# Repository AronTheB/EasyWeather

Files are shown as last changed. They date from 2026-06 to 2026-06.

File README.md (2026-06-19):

# ESP32 and BME280 based temperature, humidity, and barometric pressure measurer

## Zine
Zine

## Description

### Made for [Fallout](https://fallout.hackclub.com/) during a online weekend hackathon

### Why did i make this

I always had this idea, because i never know what to wear outside before leaving my house and I can't be hassled to check the weather app, so i will place this at the door window, so i can look and and check the temperature and other weather stats before leaving.

### How to build

Download the Gerber files and the 3d models and print them out. (I recomend JLCPCB and Prining Leigion). Order all the parts from the BOM section. After everything arrives solder the components togeather with the board and put the PCB in the case and Screw it in with a 2mm Screw. After close the box and screw it in with 3mm Screws. Connect the ESP32 to your computer and flash it with the firmware.

### How to use

After flashing it, turn the ESP32 back on and it should start automaticly. If everything worked out it should start showing the data on the OLED screen.

## KICAD

### Schematic



### PCB layout



### PCB Render (Front/Back)



## FUSION (Front/Back)



## BOM

| NAME | LINK | PRICE | QUANTITY | Need To buy? |
|---|---|---|---|---|
| XIAO ESP32-S3 | [AliExpress](https://www.aliexpress.com/item/1005007341749305.html) | $10,35 | 1 | Yes |
| BME280 | [AliExpress](https://www.aliexpress.com/item/1005006982994037.html) | $1,82 | 1 | Yes |
| 4,7k Resistors | [AliExpress](https://www.aliexpress.com/item/1005007345052730.html) | $1,36 | 1 | Yes |
| 3D Case | JLC3DP | $2,79 | 1 | Yes |
| PCB | JLCPCB | $5,00 | 1 | Yes |
| **TOTAL** | | **$23,53** | | |

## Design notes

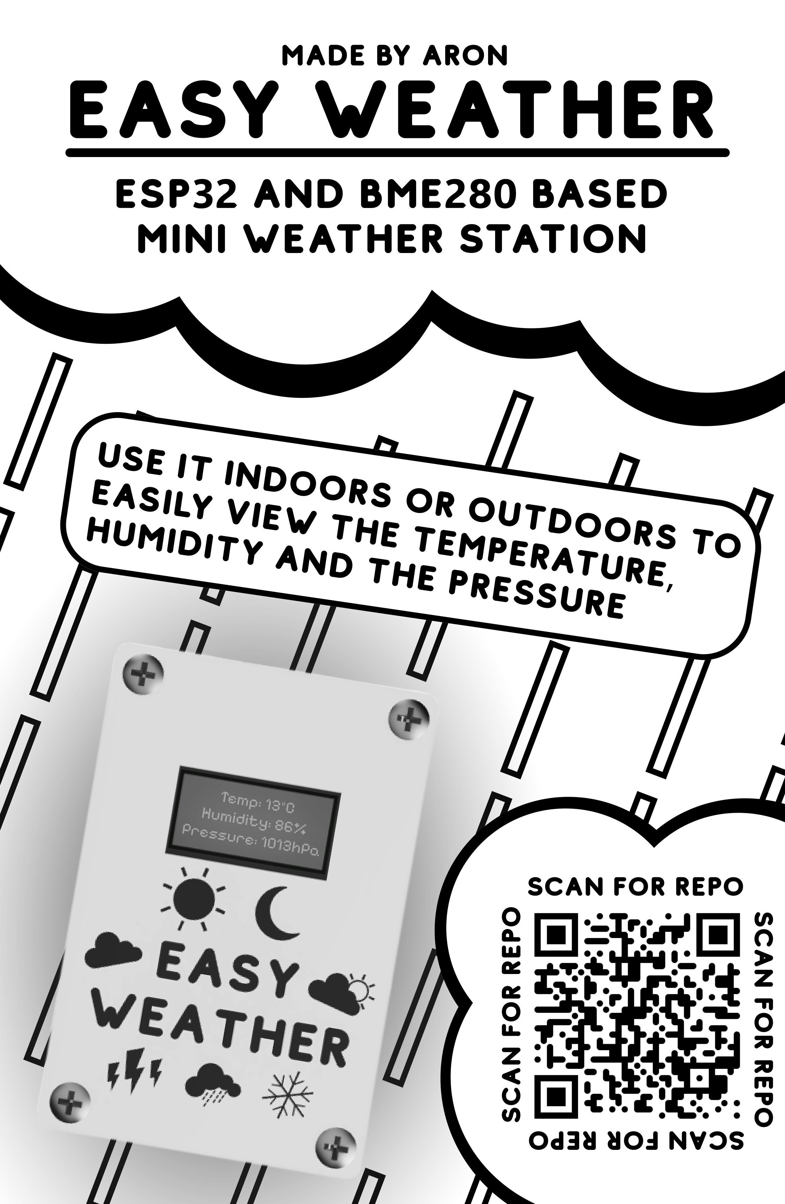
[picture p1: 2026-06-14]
Zine/Zine.jpg

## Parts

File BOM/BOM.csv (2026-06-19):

NAME | LINK | PRICE | QUANTITY | Need To buy?
XIAO ESP32-S3 | https://www.aliexpress.com/item/1005007341749305.html | $10,35 | 1 | Yes
BME280 | https://www.aliexpress.com/item/1005006982994037.html | $1,82 | 1 | Yes
4,7k Resistors | https://www.aliexpress.com/item/1005007345052730.html | 1,36 | 1 | Yes
3D Case | JLC3DP | $2,79 | 1 | Yes
PCB | JLCPCB | $5,00 | 1 | Yes
TOTAL: |  | $23,53

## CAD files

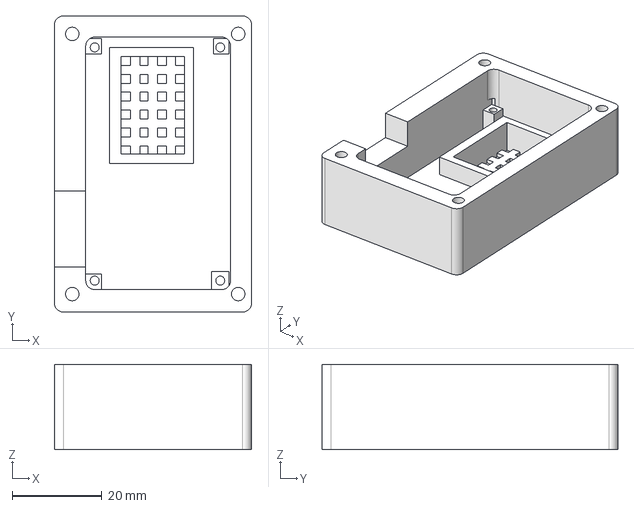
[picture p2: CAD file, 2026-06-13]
CAD/EasyWeatherBottom.step
44.0 x 66.0 x 19.0 mm

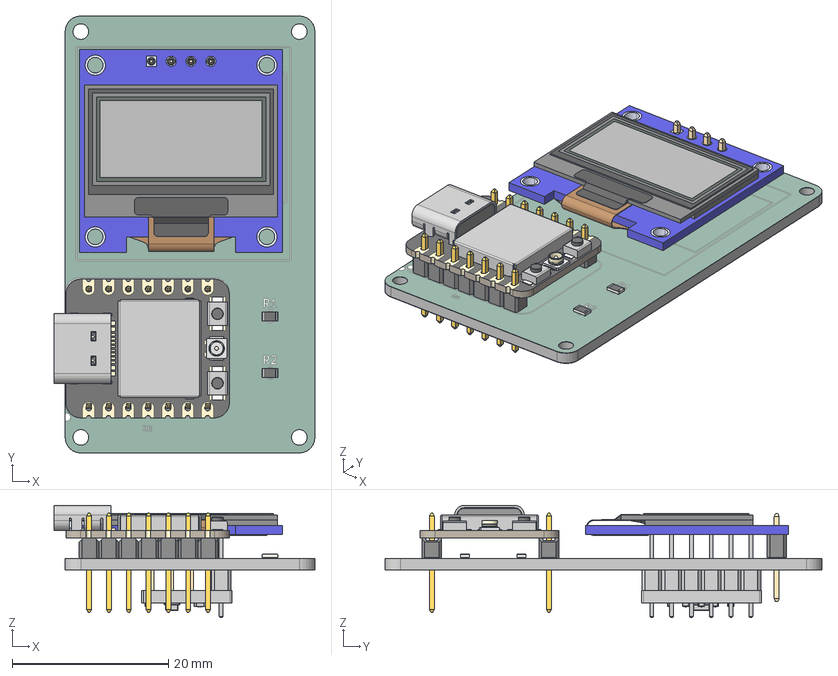
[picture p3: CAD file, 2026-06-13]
PCB/EasyWeather.step
33.4 x 56.0 x 14.4 mm
R_0805_2012Metric x 2
DM-OLED096-636_Module
DM-OLED096-636_Panel
BOSS-EXTRUDE14_8_
BOSS-EXTRUDE7_4_
BOSS-EXTRUDE7_3_
BOSS-EXTRUDE14_4_
BOSS-EXTRUDE14_2_
BOSS-EXTRUDE14_11_
BOSS-EXTRUDE7_7_
BOSS-EXTRUDE14_9_
BOSS-EXTRUDE14_3_
BOSS-EXTRUDE14_7_
MIRROR2
BOSS-EXTRUDE14_5_
BOSS-EXTRUDE14_12_
BOSS-EXTRUDE7_8_
BOSS-EXTRUDE7_1_
BOSS-EXTRUDE14_10_
BOSS-EXTRUDE7_9_
BOSS-EXTRUDE14_6_
BOSS-EXTRUDE14_1_
BOSS-EXTRUDE7_6_
BOSS-EXTRUDE7_2_
CUT-EXTRUDE5
BOSS-EXTRUDE7_5_
U.FL Connector v1
Button (1) x 2
Shield
EasyWeather_silkscreen x 2
EasyWeather_soldermask x 2
EasyWeather_PCB

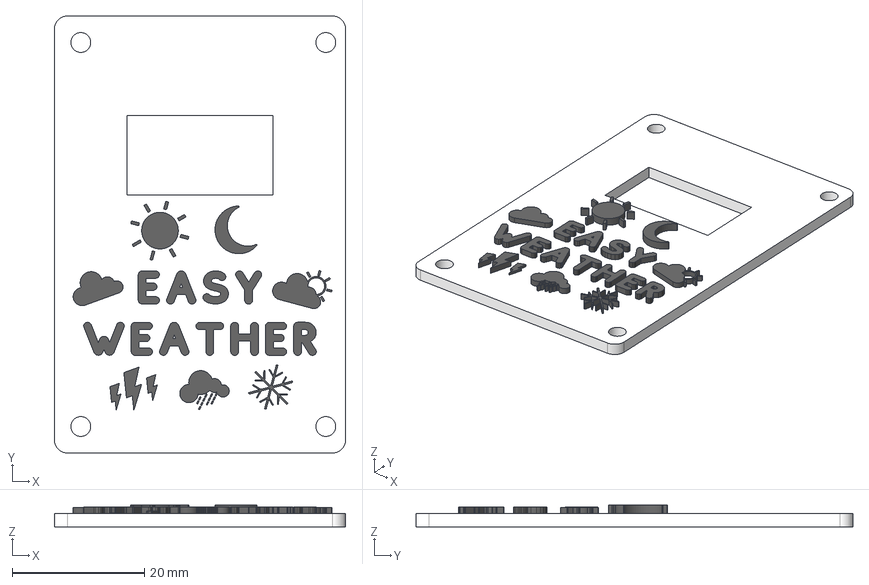
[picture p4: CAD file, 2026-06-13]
CAD/EasyWeatherTop.step
44.0 x 66.0 x 3.28 mm

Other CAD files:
CAD/EasyWeatherBottom.f3z

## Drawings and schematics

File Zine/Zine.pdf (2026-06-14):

# EASY WEATHER Made by Aron

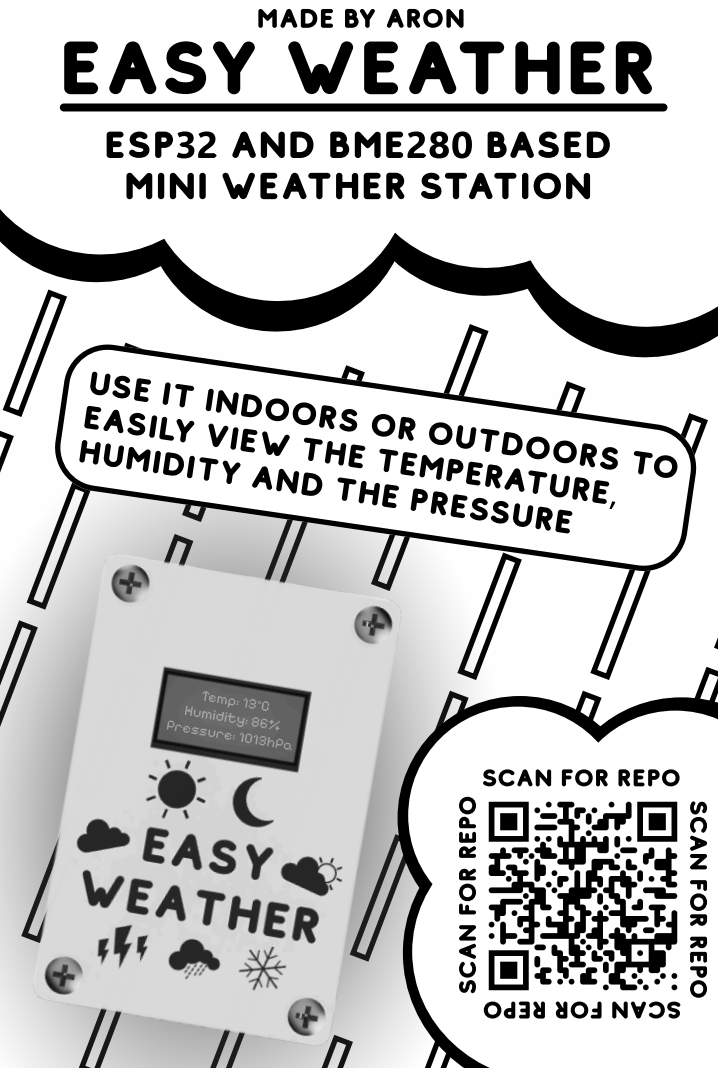
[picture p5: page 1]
Temp: 13°C Humidity: 86% Pressure: 1013hPa; SCAN; FOR REPO

ESP32 and BME280 based
mini weather station

Use it indoors or Outdoors to

easily view the temperature,

humidity and the pressure

SCAN FOR REPO

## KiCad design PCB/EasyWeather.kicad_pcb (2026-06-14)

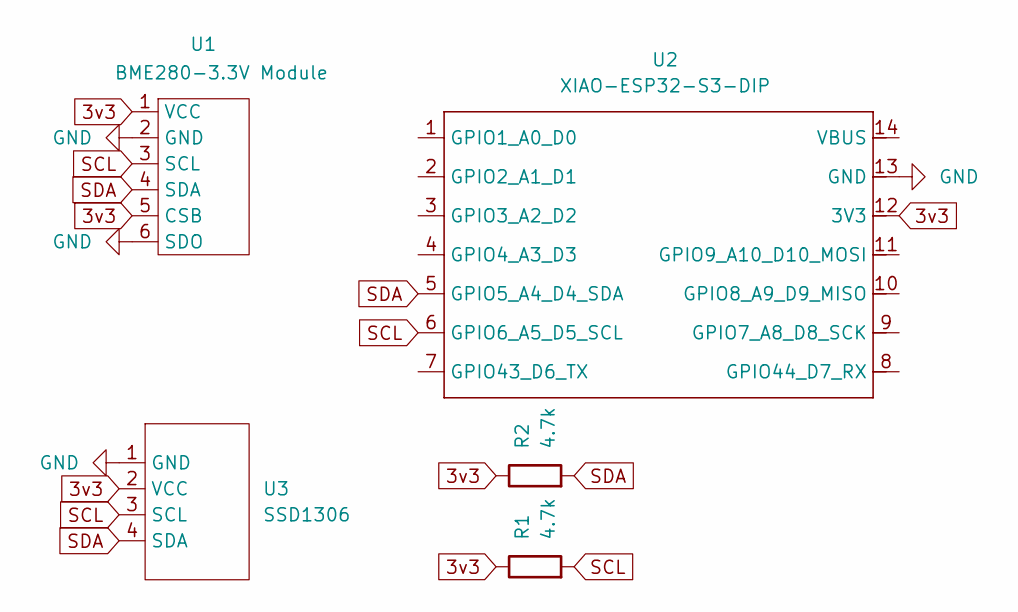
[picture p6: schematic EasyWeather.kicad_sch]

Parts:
R1, R2: 4.7k; R_0805_2012Metric_Pad1.20x1.40mm_HandSolder
U1: BME280-3.3V Module; BME280-3.3V
U2: XIAO-ESP32-S3-DIP
U3: SSD1306; 128x64OLED

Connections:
3v3: R1.1, R2.1, U1.1 (VCC), U1.5 (CSB), U2.12 (3V3), U3.2 (VCC)
GND: U1.2 (GND), U1.6 (SDO), U2.13 (GND), U3.1 (GND)
SCL: R1.2, U1.3 (SCL), U2.6 (GPIO6_A5_D5_SCL), U3.3 (SCL)
SDA: R2.2, U1.4 (SDA), U2.5 (GPIO5_A4_D4_SDA), U3.4 (SDA)

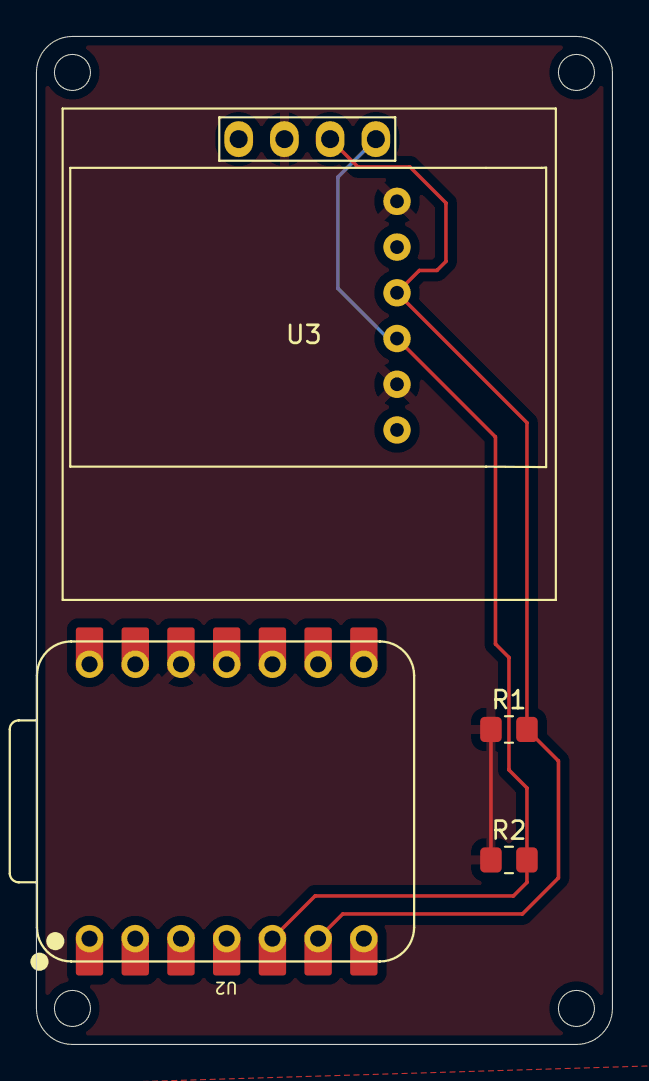
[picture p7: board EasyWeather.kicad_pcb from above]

Board: 2 copper layers, 32.0 x 56.0 mm, 5 parts (1 on the bottom side), 4 nets.

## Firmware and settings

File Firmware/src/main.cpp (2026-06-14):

#include <Wire.h>
#include <Adafruit_Sensor.h>
#include <Adafruit_BME280.h>
#include <WiFi.h>
#include <Adafruit_SSD1306.h>

#define SEALEVELPRESSURE_HPA (1013.25)
#define SCREEN_WIDTH 128
#define SCREEN_HEIGHT 64
#define OLED_RESET -1
Adafruit_SSD1306 display(SCREEN_WIDTH, SCREEN_HEIGHT, &Wire, OLED_RESET);
Adafruit_BME280 bme; // I2C

const char* ssid = "123";
const char* password = "123";
WiFiServer server(80);

unsigned long delayTime;

void setup() {
    Serial.begin(9600);
    Serial.println(F("BME280 test"));

    if (! bme.begin(0x77, &Wire)) {
        Serial.println("Could not find a valid BME280 sensor, check wiring!");
        while (1);
    }

    if (!display.begin(SSD1306_SWITCHCAPVCC, 0x3C)) {
        Serial.println("Could not find SSD1306!");
        while (1);
    }
    display.clearDisplay();
    display.setTextColor(SSD1306_WHITE);

    display.setTextSize(1);
    display.setCursor(0, 0);
    display.print("Connecting WiFi...");
    display.display();

    Serial.print("Connecting to ");
    Serial.println(ssid);
    WiFi.begin(ssid, password);
    while (WiFi.status() != WL_CONNECTED) {
      delay(500);
      Serial.print(".");
    }

    display.clearDisplay();
    display.setCursor(0, 0);
    display.print("WiFi connected!");
    display.setCursor(0, 10);
    display.print(WiFi.localIP());
    display.display();
    delay(2000);

    server.begin();
    delayTime = 5000;
}

void loop() {
    bme.takeForcedMeasurement();
    
    printValues();
    delay(delayTime);
}

// Add webserver later
void printValues() {
    float temperature = bme.readTemperature();
    float humidity = bme.readHumidity();
    float altitude = bme.readAltitude(SEALEVELPRESSURE_HPA);
    float pressure = bme.readPressure() / 100.0F;

    Serial.printf("Temp: %.1f C | Pressure: %.1f hPa | Alt: %.1f m | Hum: %.1f%%\n",temperature, pressure, altitude, humidity);

    display.clearDisplay();
    display.setTextSize(1);
    display.setCursor(0, 0);
    display.printf("Temp: %.1f C\n", temperature);

    display.setCursor(0, 16);
    display.printf("Pressure: %.1f hPa\n", pressure);

    display.setCursor(0, 32);
    display.printf("Humidity: %.1f%%\n", humidity);

    display.setCursor(0, 48);
    display.printf("Altitude: %.1f m\n", altitude);

    display.display();
}

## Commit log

2026-06-13 moved to PCB folder
    [EasyWeather.kicad_pcb, EasyWeather.kicad_sch]
2026-06-13 Enhance README with project details and images
    Added detailed project description, including purpose and images of schematic and PCB layout.
2026-06-14 Add BOM section to README
    Added a BOM section with components, links, prices, and quantities.
2026-06-14 new gerber
2026-06-19 Update 3D Case supplier and price in README
2026-06-19 Update BOM.csv with new 3D Case supplier and price
    [BOM.csv]
